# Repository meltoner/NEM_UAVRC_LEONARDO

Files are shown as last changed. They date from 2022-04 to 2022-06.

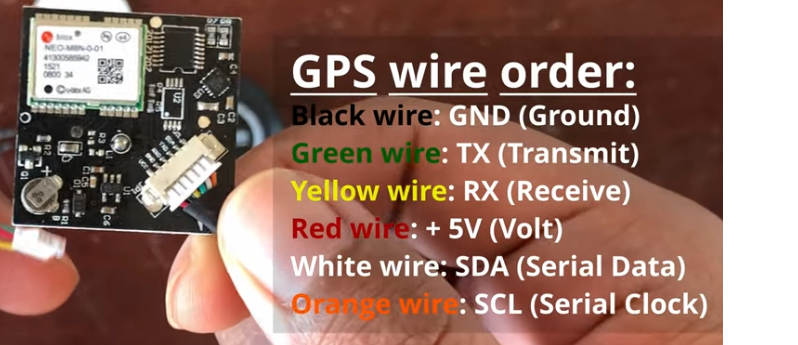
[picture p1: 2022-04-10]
research/gps-pins.png

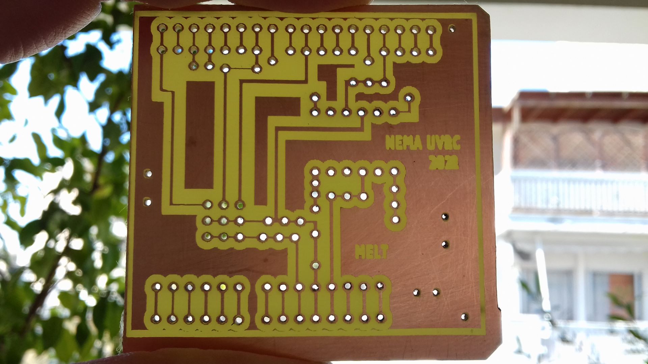
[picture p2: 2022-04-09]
pcb/pcb-snapshot.jpg

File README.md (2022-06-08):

# NEM Unmanned Vehicle Remote controlled - UAVRC

## Software Features :

- Software utilises an MPU, GPS, Servo, ESC, magnetometer and a remote control input, in an arduino leonardo.
- Sensors and accuators are all in classes
- Considers seven interval / frequencies of task execution
- Controls steering based on target 
- Boots esc motor, and applies a non liner transfer function to the speed remote input
- Computes degrees heading at boot time, used as an offcet for the mpu degree heading
- Derives distance and degree from a target gps LAT LOT
- Return to home on signal loss
- pending-Detection of low battery and return to home

## Hardware

Sensors :

- Gps : M8n
- Magmetometer : M8n's HMC5883
- Receiver : flysky F9-ia10b
- MPU : MPU6050
- Voltage sensor 0-25v MH-electronic

Other: 
- Transmitter : flysky FS-I6X
- Arduino Leonardo
- Sparkfun Logic Level Converter Bi-Directional

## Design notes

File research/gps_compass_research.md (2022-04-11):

-------
notes on incorporating also the magnetometer of the gps ublox m8n
==
https://www.youtube.com/watch?v=BVP0ny55STQ

HMC5883L is used in ublox 
or the ist8310 

https://www.youtube.com/watch?v=vPGChdmfKl0

https://github.com/kriswiner/MPU6050/wiki/Affordable-9-DoF-Sensor-Fusion
https://github.com/kriswiner/MPU6050HMC5883AHRS

https://forum.arduino.cc/t/arduino-mpu6050-hmc5883l/631657/5

https://howtomechatronics.com/tutorials/arduino/how-i2c-communication-works-and-how-to-use-it-with-arduino/

magnetometer address 0x1E
mpu 0x68

either one is scanned not at the same time - when both only the 0x68 is udentified

https://www.ti.com/lit/an/slva704/slva704.pdf
https://www.circuitbasics.com/basics-of-the-i2c-communication-protocol/

https://learn.sparkfun.com/tutorials/i2c/all
https://www.sparkfun.com/products/12009?_ga=2.167635646.1082899826.1648417824-1013542653.1638983343

https://electropeak.com/learn/interfacing-gy-87-10dof-imu-mpu6050-hmc5883l-bmp085-module-with-arduino/

https://www.elecrow.com/imu-10dof-mpu6050hmc5883lbmp180-p-1238.html

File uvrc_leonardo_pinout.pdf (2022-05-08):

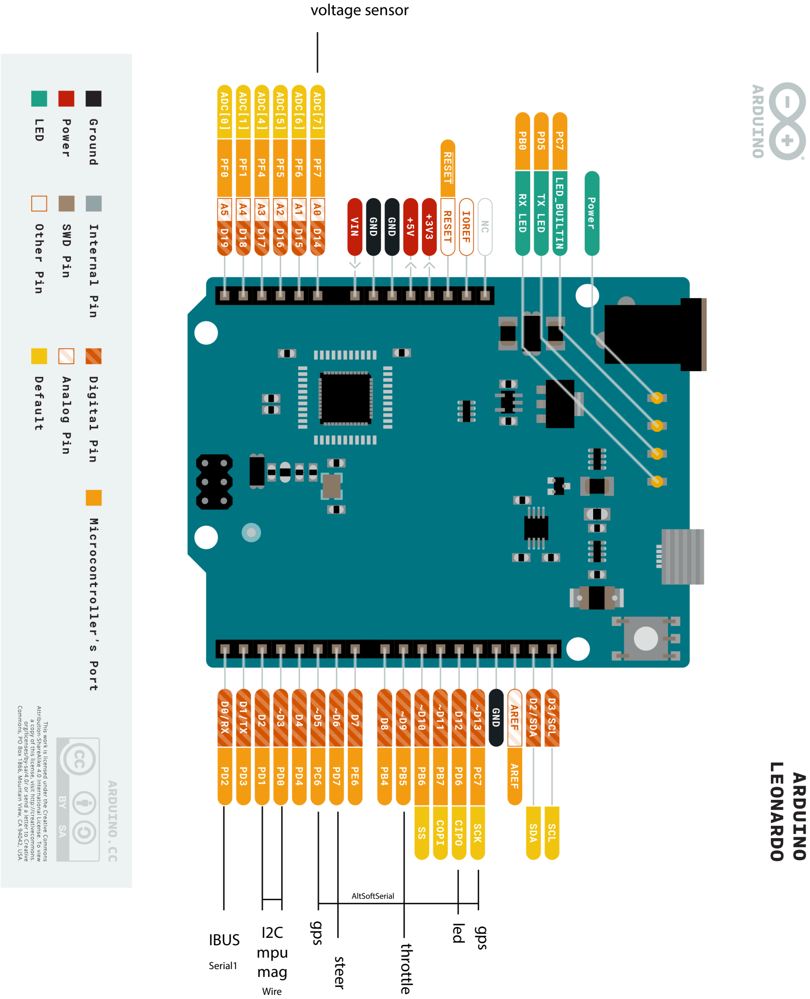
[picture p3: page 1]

IBUS I2C
mpu
mag

gps
gps

AltSoftSerial

Serial1

Wire

led

steer

throttle

voltage sensor

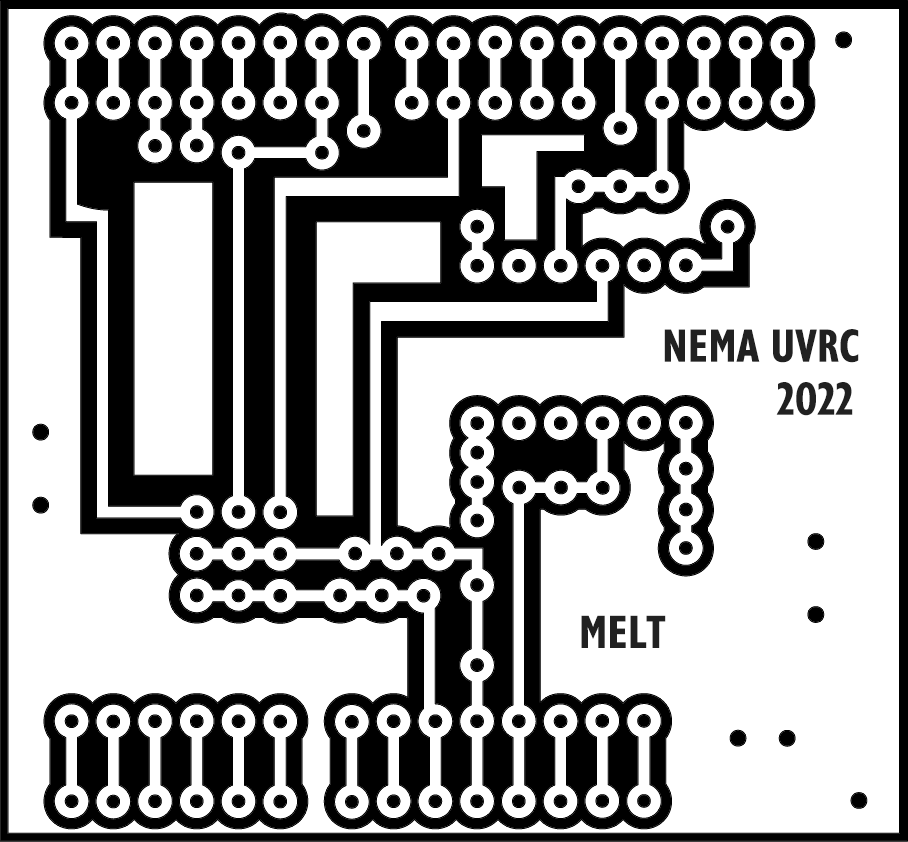
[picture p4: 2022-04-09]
pcb/4.pcb_inverted.png

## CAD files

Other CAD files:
pcb/1.pcb_rhino.3dm

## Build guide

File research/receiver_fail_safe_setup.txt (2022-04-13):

setup fail safe
menu > system > rx > failsafe > chanell 10 > on and turn on the 4th switch. save and press the update button on the receiver.

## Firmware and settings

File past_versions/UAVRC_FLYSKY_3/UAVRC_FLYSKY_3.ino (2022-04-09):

// Konstantinos Papageorgiou - 2022 - kp@rei.gr
// Code utilising MPU6050, GPS, Servo
// Considers four time intervalas - 1ms - 10, 50 , 500 and 5000
// Uses Smotthing with dynamic number of points per sensor value
// Able to derive distance and degrees from a target LAT LOT
// Controls steering throttle to achieve 30 degrees roll
// Computes actual degree of the earth, by checking the gps consequent points - when on straight line - to derive the mpu offset from time of start.
// 

#include <Smoothed.h>
#include <IBusBM.h>

#include <Wire.h>
#include <MPU6050_light.h>

#include <Servo.h>

#include <AltSoftSerial.h>
#include <TinyGPS++.h>

MPU6050 mpu(Wire);

Servo steer;
Servo throttle;
int throttleValue=0;
int steerValue=0;
int center=94;

TinyGPSPlus gps;
AltSoftSerial gpsPort; //5 ,13
IBusBM IBus; // IBus object 

#define SENSORS 7
// lat, lng, distance, degrees, x, y, z // where z matches to degres
Smoothed <float> sensors[SENSORS];
byte samples[] = {3, 3, 4, 4, 5, 5, 3};

byte ext_sensors[] = {0,0,0,0,0,0,0,0,0,0};

unsigned long now = millis();
int intervals[] = {10,50,100,500,5000};
unsigned long timers[] = {now,now,now,now,now};

boolean gpsLock = false;
//Akropoli
//double TARGET_LAT = 37.9584512;
//double TARGET_LNG = 23.7502464;
 
double TARGET_LAT = 37.966266;
double TARGET_LNG = 23.744422;


void setupSensorValues(){
   for(int i = 0; i < SENSORS; i++)
    sensors[i].begin(SMOOTHED_AVERAGE, samples[i]);
  Serial.println("Smoothed sensor values ready.");
}

void setupMPU(){
  Wire.begin();
  byte status = mpu.begin();
  Serial.print(F("MPU6050 status: "));
  Serial.println(status);
  while(status != 0){
    Serial.println("MPU6050 not detected ... Check your wiring!");
    delay(500);
  } 
  Serial.println(F("Calculating offsets, do not move MPU6050"));
  delay(4000);  
  mpu.calcOffsets(); // gyro and accelero
  Serial.println("MPU ready.");
}

void setSteer(int value){
  steerValue = value;
  steer.write(value);
}

void setupSTEER(){
  steer.attach(6); 
  setSteer(center);
  Serial.println("Steer ready.");
}

void setupTHROTTLE(){
  throttle.attach(9); 
  throttle.writeMicroseconds(900); // send "stop" signal to ESC. Also necessary to arm the ESC.
  delay(1000); // delay to allow the ESC to recognize the stopped signal.
  Serial.println("Throttle ready.");
}

void setupGPS(){
  gpsPort.begin(9600);
  Serial.println("GPS ready.");
}

void setupIBUS(){
  IBus.begin(Serial1);
  delay(200);
  Serial.println("IBUS ready.");
}

void setup() {
  setupTHROTTLE();
  Serial.begin(9600);
  delay(1000);
  setupIBUS();
  setupSensorValues();  
  setupMPU();
  
  setupSTEER();
  setupGPS();
  Serial.println("Setup done");
}

int readChannel(byte channelInput, int minLimit, int maxLimit, int defaultValue){ //https://www.youtube.com/watch?v=JZQoHmLqZYg
  uint16_t ch = IBus.readChannel(channelInput);
  if (ch < 100) return defaultValue;
  return map(ch, 1000, 2000, minLimit, maxLimit);
}

void updateIBUS(){
  for(int i = 0; i < 10; i++)
   ext_sensors[i] = (byte)readChannel(i, 0, 255, 0);  
}

void setThrottle(int value){
  if(value > ext_sensors[4])
    value = ext_sensors[4];
  throttleValue = value;
  int pwmVal = map(value, 0, 255, 1000, 2000); // maps to PWM value.
  throttle.writeMicroseconds(pwmVal); // Send signal to ESC.
}

int degree=0;
void updateMPU() {  
    sensors[4].add(mpu.getAngleX());
    sensors[5].add(mpu.getAngleY());
    sensors[6].add(mpu.getAngleZ()); 
    degree = -((int)sensors[6].get()) % 360;
    if(degree<0)degree+=360;
}

int target = 0;

int getDegreeDiff(){
     int diff = target-degree;
     if(diff>180)
      diff=diff-360;
     if(diff<-180)
      diff=diff+360;
            
     if(diff>45)
      diff=45;
     if(diff<-45)
      diff=-45;
    return diff;
}

void updateSteer(){
   int control = map(ext_sensors[0], 0, 255, -50, 50);
   if(hasTarget()){
      setSteer(center - getDegreeDiff());
   }else{
      setSteer(center - control );
   }
}

int transferFunction(int value, int theshold, int add, int divider){
   float x = (float)value;    
    if(x<theshold){
      x = 0;
    }else{
      x=x+add;
      x = (x * (x/divider))+(10/2);
    }
    return (int)x;
}

void updateThrottle(){
    setThrottle(transferFunction(ext_sensors[2], 15, 20, 300)); 
}

boolean hasTarget(){
  return ext_sensors[6] == 255 ;
}

boolean isSwitchCHalf(){
   return ((int)ext_sensors[8]) == 127;
}

boolean isSwitchCFull(){
  return ext_sensors[8] == 255 ;
}

boolean updateGpsDegreeTarget(){
  if(isSwitchCHalf())
   target = (int)sensors[3].get();
  if(isSwitchCFull() && gpsLock){
    TARGET_LAT = sensors[0].get();
    TARGET_LNG = sensors[1].get();
  }
}


boolean hasNewDegree(){
  if(hasTarget()){
    int control = map(ext_sensors[0], 0, 255, 0, 40)-20;
    if(abs(control)>2 && !(isSwitchCHalf()))
      target+=control/2;
  }
  if(ext_sensors[7] == 255)
    target=degree;
}

void updateGPS(){
   while (gpsPort.available())
      gps.encode(gpsPort.read());   

   if(!gpsLock && gps.location.lat() != 0.0)
     gpsLock = true;
   
   if(gpsLock){
     sensors[0].add(gps.location.lat());
     sensors[1].add(gps.location.lng());
     returnHome();
   }
}

//-----------------------------------------




void returnHome(){    
    double distanceKm =
      gps.distanceBetween(
        sensors[0].get(),
        sensors[1].get(),
        TARGET_LAT,
        TARGET_LNG) / 1000.0;
    
    double courseTo =
      gps.courseTo(
        sensors[0].get(),
        sensors[1].get(),
        TARGET_LAT,
        TARGET_LNG);
    
    sensors[2].add(distanceKm*1000);
    sensors[3].add(courseTo);

}

void run_invoker(){  
  mpu.update();  
  now = millis();
  for(int i = 0; i < 4; i++){
   if ((now - timers[i]) > intervals[i]) {
    timers[i] = now;
    switch(i){
      case 0: apply_very_fast_invoker(); break;
      case 1: apply_fast_invoker(); break;
      case 2: apply_invoker(); break;
      case 3: apply_slow_invoker(); break;
      case 4: apply_very_slow_invoker(); break;
    }
   }
  }
}

void printSensors(){
  for(int i = 0; i < SENSORS; i++){
    if(i<2)
      Serial.print(sensors[i].get(), 6);
    else
      Serial.print(sensors[i].get(), 2);
   Serial.print(" ");
  }
  for(int i = 0; i < 10; i++){
   Serial.print(ext_sensors[i]);
   Serial.print(" ");
  }
  Serial.print(throttleValue);
  Serial.print(" ");

  Serial.print(steerValue);
  Serial.print(" ");

  Serial.print(target); 
  Serial.println(""); 
}

void apply_very_fast_invoker(){
   updateMPU();   
}

void apply_fast_invoker(){
   updateIBUS();
   updateSteer();
   updateThrottle();
}
void apply_invoker(){   
  hasNewDegree();
  updateGpsDegreeTarget();
}
void apply_slow_invoker(){
  updateGPS();
  printSensors(); 
}

void apply_very_slow_invoker(){
}

void loop(){ 
 run_invoker();
}

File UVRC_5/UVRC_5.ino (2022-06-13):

// Konstantinos Papageorgiou - 2022 - kp@rei.gr
//
// # NEM Unmanned Vehicle Remote controlled - UVRC
// 
// ## Software Features :
// 
// - Software utilises an MPU, GPS, Servo, ESC, magnetometer and a remote control input, in an arduino leonardo.
// - Sensors and accuators are all in classes
// - Considers seven interval / frequencies of task execution
// - Controls steering based on target 
// - Boots esc motor, and applies a non liner transfer function to the speed remote input
// - Computes degrees heading at boot time, used as an offcet for the mpu degree heading
// - Derives distance and degree from a target gps LAT LOT
// - Return to home on signal loss
// - pending-Detection of low battery and return to home
// 
// ## Hardware
// 
// Sensors :
// 
// - Gps : M8n
// - Magmetometer : M8n's HMC5883
// - Receiver : flysky F9-ia10b
// - MPU : MPU6050
// - Voltage sensor 0-25v MH-electronic
// 
// Other: 
// - Transmitter : flysky FS-I6X
// - Arduino Leonardo
// - Sparkfun Logic Level Converter Bi-Directional

#include "Context.h"
#include "Invoker.h"

#include "Mag.h"
#include "Gps.h" 
#include "Mpu.h" 
#include "Steer.h"
#include "Throttle.h"
#include "Remote.h"
#include "Home.h"
#include "Blink.h"
#include "Battery.h"
#include <EEPROM.h>

Context context(0);
Invoker invoker(0);

Mag mag(0);
Gps gps(0);
Mpu mpu(4);
Steer steer(6);
Throttle throttle(9);
Remote remote(0);
Home home(0);
Blink blink(0);
Battery battery(0);

//-----------------------------------------

void setup() {

  context.setup();
  blink.setup(context);
  throttle.setup(context);
  delay(2000);
  mpu.setup(context);
  delay(2000);

  //Serial.println(F("Powering up"));
  remote.setup(context);
  mag.setup(context);
  steer.setup(context);
  gps.setup(context);
  battery.setup(context);
  home.setup(context);
  invoker.setup(context);
  //Serial.println(F("Setup done"));

}

void apply_very_fast_invoker(){
  mag.apply();
  mpu.apply();
}

void apply_fast_invoker(){
  remote.apply();
  steer.apply();
  throttle.apply();
}

void apply_invoker(){
  gps.apply();
  //steer.hasNewDegree();
  home.apply();
}

void apply_slow_invoker(){
  context.apply(); // every 0.5 second printout / log enviromental variables
  remote.telemetry(); 
}

void heartBeat(){
  //dynamic periodicity 
  // Every : 3s when no gps, 1sec when gps lock, 0.5 seconds when returing to home is active, 0.1 second when power is less than 30%.
  blink.apply();
}

void apply_slower_invoker(){
  //every 1 second
  home.apply();
  battery.apply();
}

void updateMagOffset(){
  //10 seconds period
  if(context.toHomeActive)
    mag.updateMagOffset();
}

void run_invoker(int i){
    switch(i){
      case 0: apply_very_fast_invoker(); break;
      case 1: apply_fast_invoker(); break;
      case 2: apply_invoker(); break;
      case 3: apply_slow_invoker(); break;
      case 4: apply_slower_invoker(); break;
      case 5: heartBeat(); break;
      case 6: updateMagOffset();break;
      case 7: home.bursts();break;
      case 100: break;
    }
}

void loop(){
  mpu.update(); 
  int actionIndex = invoker.apply();
  while(actionIndex != 100){
    run_invoker(actionIndex);
    actionIndex = invoker.apply();
  }
}

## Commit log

2022-04-16 Add files via upload
    Auto-corrective heading
    [Context.cpp, Context.h, Mpu.cpp]
2022-04-26 Add files via upload
    crucial bug, random freezes fix, sources at i2c and mpu6050, addressed by timeout setting
    return to home modularization
    blink module reflecting the health status
    [Context.cpp]
2022-04-30 Add files via upload
    Adding a battery voltage sensor - in progress
    Enable variable intervals of functions
    Dynamic blink interval as heartbeat : no gps 2s, gps lock 1s, returning to home 0.5second
    Documentation on context to string serial print
2022-04-30 Add files via upload
    Battery voltage to capacity estimation implementation 6v to 7.4 volt mapped to 0-100%
2022-05-01 Add files via upload
    Energy saving improvement powering off servo steering, when at center for more than 1 second
2022-05-02 Add files via upload
    Energy improvement - incremental throttle acceleration, when requested is large
2022-05-08 Add files via upload
    arduino leonardo connectivity sensors
2022-06-13 Add files via upload
    transformation function reuse
    function invocation may not be trigger-able in all cases - fix
    [Context.cpp, Context.h, Mpu.cpp]
